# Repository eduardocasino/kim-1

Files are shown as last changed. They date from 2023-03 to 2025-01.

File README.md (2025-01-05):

# KIM-1 Replica

## Introduction

Welcome to the MOS KIM-1 reproduction project repository, where you will find what aims to be a faithful replica of the MOS KIM-1 computer, in particular a revision "D" PCB, based on photos and information gathered from various sources on the internet. With minimal modifications, later revisions should be easy to reproduce as well.

The KIM-1 was a single-board computer released in 1976 by MOS Technology, later acquired by Commodore, as a demonstrator of the capabilities of the recently released 6502 microprocessor.

## About

This recreation has been an excruciating process using entirely free software: Inkscape, Kicad and Freecad.

First, a high resolution image of a KIM-1 was used as a template in Inkscape. The image was resized to scale using the IC footprints as a reference. Then, the rest of the footprints were placed and the tracks were traced using bézier curves. I used a layer for each type graphic components (footprints, tracks, copper zones, typography, ...)

The logo was created from the MOS logo, adding the commodore name with the [Eurostile Extended 2 Bold font](https://fontsgeek.com/fonts/eurostile-extended-2-bold).

Component references where placed with the [Futura STD Bold font](https://fontsgeek.com/fonts/Futura-Std-Bold). The [Arial-like Aria font](https://fontsgeek.com/aria_1-font) was used for other typography.

The inkscape image was imported from Kicad to an user layer and used as a template for placing the footprints. Then, the image with the tracks was imported to the copper layer and converted to kicad tracks, so it was possible to check the pcb against the schematic.

The logo and the typography were converted to footprints using the svg2shenzhen plugin.

This is the end result:

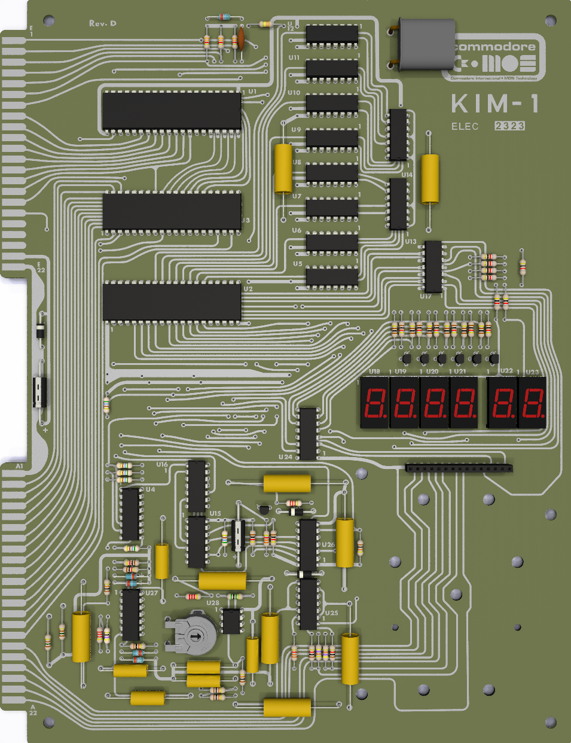
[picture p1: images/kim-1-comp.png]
components

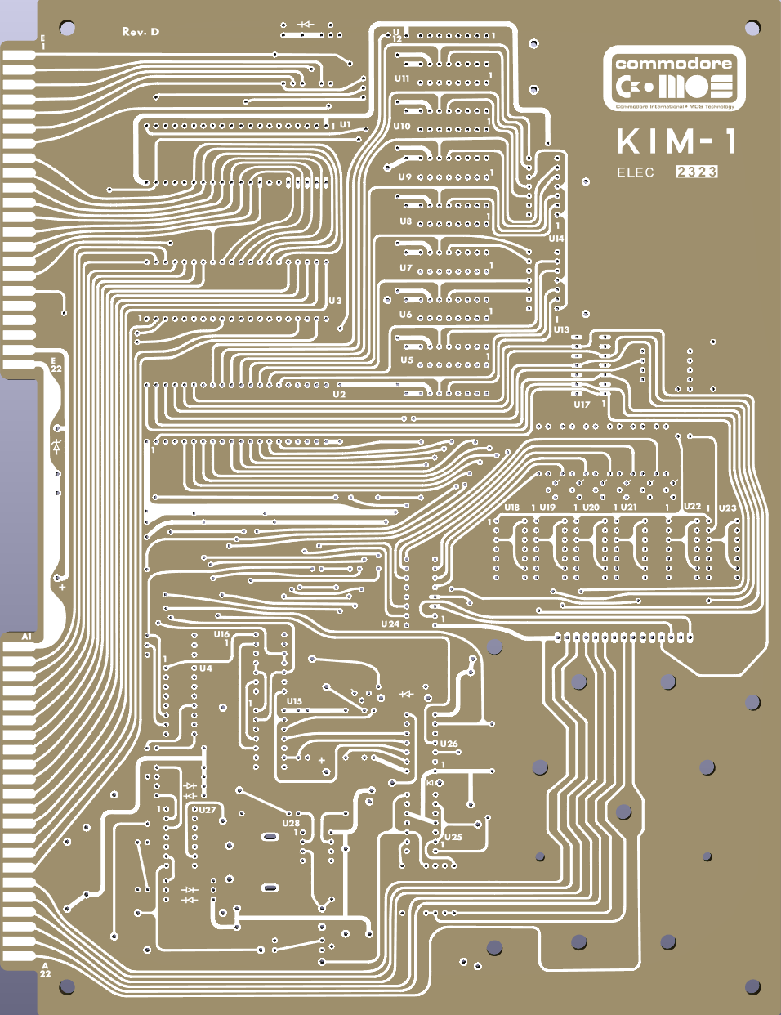
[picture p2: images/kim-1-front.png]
front

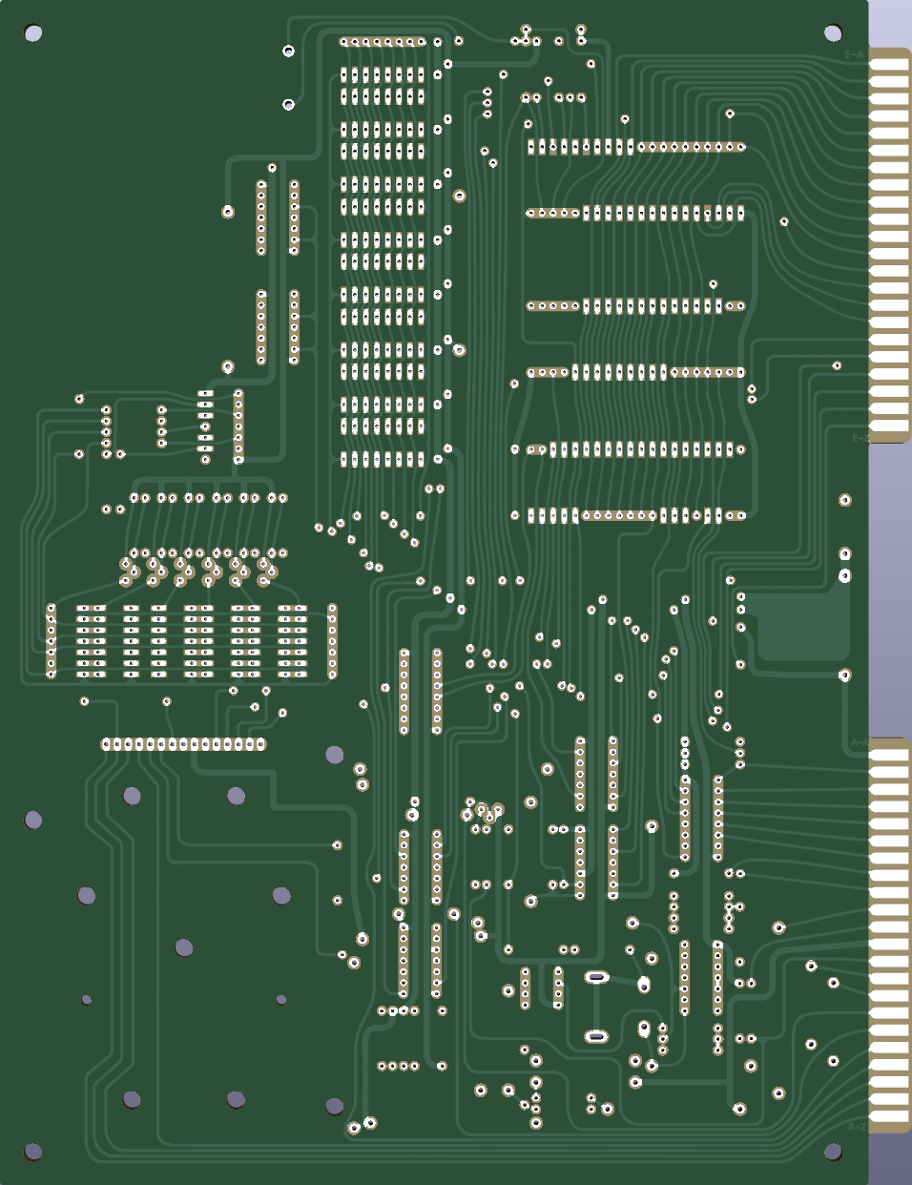
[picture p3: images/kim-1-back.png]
back


The replica has been successfully built and tested. Here is a picture of the KIM-1 working with [my dual 6530-6532 adapter](https://github.com/eduardocasino/kim-1-dual-6532-adapter) and [my work-in-progress kim-1 keypad](https://github.com/eduardocasino/kim-1-keypad):

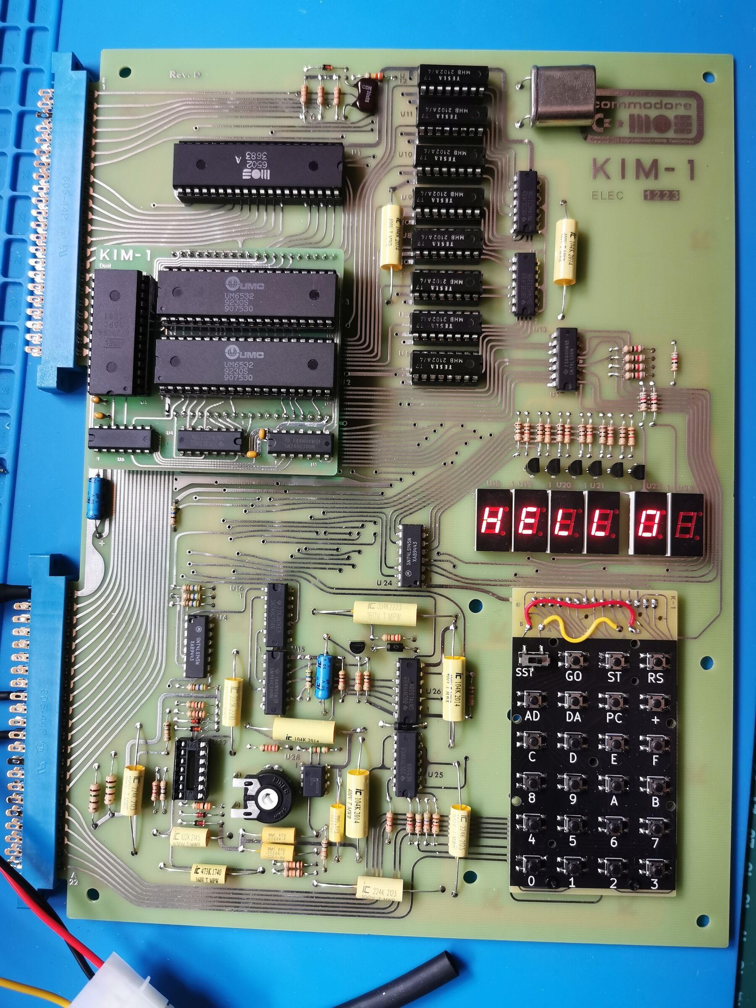
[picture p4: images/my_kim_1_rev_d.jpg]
KIM-1 replica working


## Building

[Paul Sajna](https://github.com/sajattack) has created an [Octopart BOM](https://octopart.com/bom-tool/09w2sZzv), with direct distributor links, to ease the sourcing of the components. Take into account that there are some obsolete parts that are no longer available, so you'll have to look on eBay or Aliexpress for them. Just be careful with counterfeits!

## Licensing

This is a personal project that I am sharing in case it is of interest to any retrocomputing enthusiast and all the information in this repository is provided "as is", without warranty of any kind.  



This work is licensed under a [Creative Commons Attribution-NonCommercial 4.0 International License](http://creativecommons.org/licenses/by-nc/4.0/).

EXCEPTION: The electrical schematic and all the associated symbols are licensed under a [Creative Commons Attribution 4.0 International License](https://creativecommons.org/licenses/by/4.0/).

See the LICENSE.md file for details.

## Changelog

#### 23/05/2023

* Fix position of mounting holes

#### 07/06/2023

* Fix tracks that weren't correctly imported from SVG
* Bump date stamp to week 2323
* Add interactive BOM

## Acknowledgements

* Hans Otten and his [Retro Computing blog](http://retro.hansotten.nl/). Tons of information and high resolution pictures of various KIM-1
* Chuck Hutchins, for his [hi-res scans of an unpopulated Rev. D PCB](http://retro.hansotten.nl/6502-sbc/kim-1-manuals-and-software/kim-1-revisions/)
* Budi Prakosa "badgeek" for the [svg2shenzhen](https://github.com/badgeek/svg2shenzhen) plugin for Inkscape
* qu1ck for his [interactive HTML BOM plugin](https://github.com/openscopeproject/InteractiveHtmlBom)
* Ralf (User ralf02 from forum64.de) for info on actual dimensions of a KIM-1 and ideas from [his thread on a KIM-1 clone](https://www.forum64.de/index.php?thread/124855-instandsetzung-und-nachbau-eines-kim-1/).
* [Armin Hierstetter](https://www.apple-1-replica.com/) for measurements of the mounting holes 
* [Paul Sajna](https://github.com/sajattack), for the Octopart BOM.

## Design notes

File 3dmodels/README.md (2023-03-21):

Donload the PT-15 potentiometer 3D model from here: https://www.piher.net/products/contacting-position-sensors/trimmers-and-control-potentiometers/through-hole/pt-15/

Make sure that the file is named PT15LV18.STEP

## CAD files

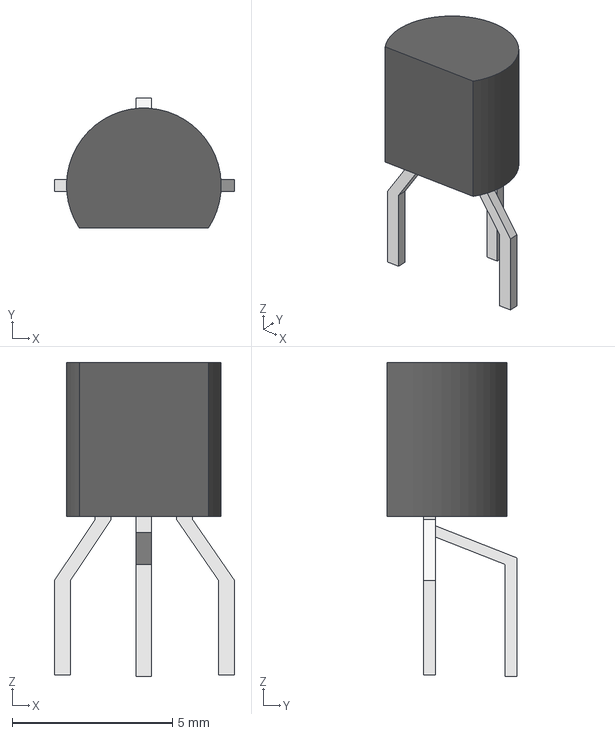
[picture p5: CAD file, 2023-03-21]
3dmodels/TO-92.step
5.62 x 4.06 x 9.80 mm

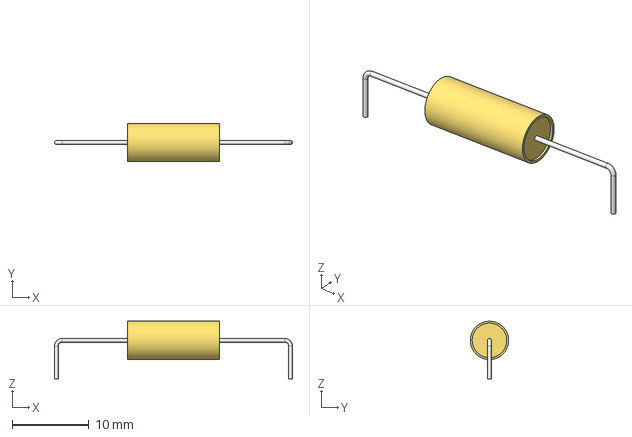
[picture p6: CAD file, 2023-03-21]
3dmodels/C_Axial_L12.0mm_D5.0mm_P30.48mm_Horizontal.step
31.0 x 5.00 x 7.50 mm
190bb9be-b13a-11ed-bc6f-67ea0efcc404_part
190bb9bf-b13a-11ed-bc6f-67ea0efcc404_part

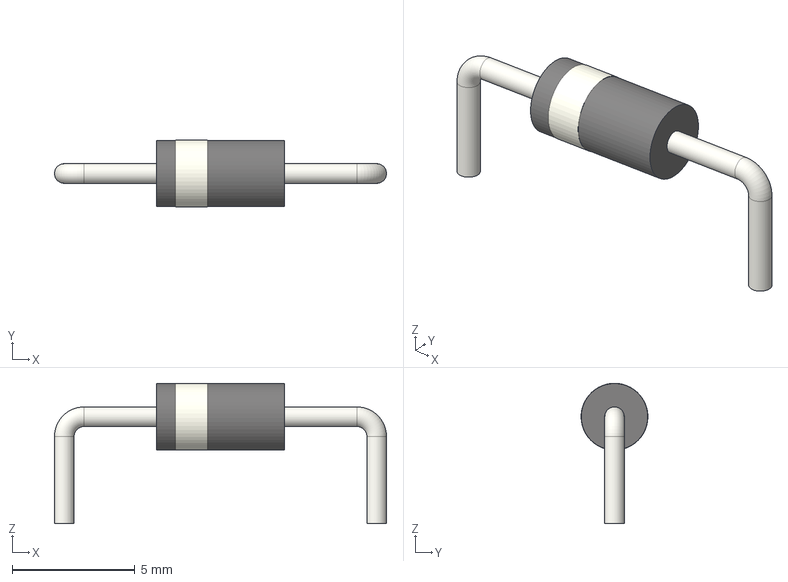
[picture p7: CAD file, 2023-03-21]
3dmodels/D_DO-41_SOD81_P12.30mm_Horizontal.step
13.5 x 2.72 x 5.71 mm

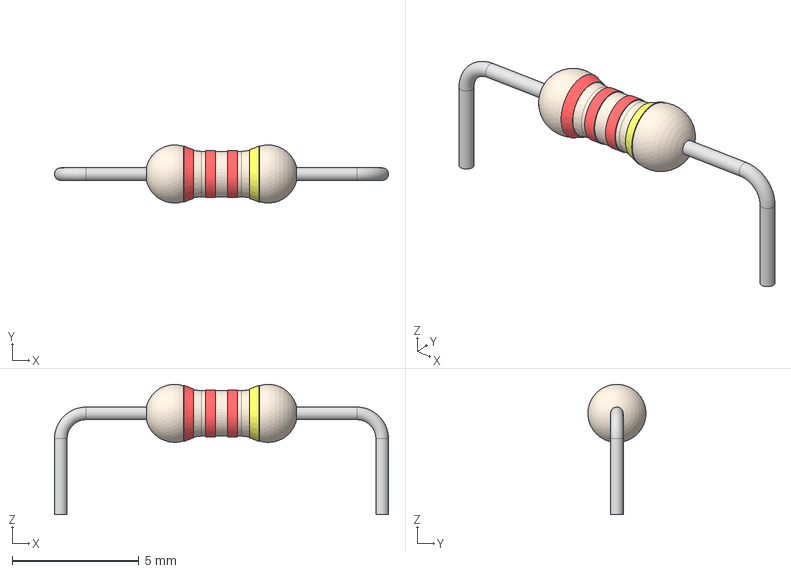
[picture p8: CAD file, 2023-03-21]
3dmodels/res-1_4w-2K2-12_7mm-Resistor-1_4w-220ohm.step
13.2 x 2.29 x 5.14 mm
Resistor-body
Ring-1
Ring-2
Ring-3
Ring-4
pins

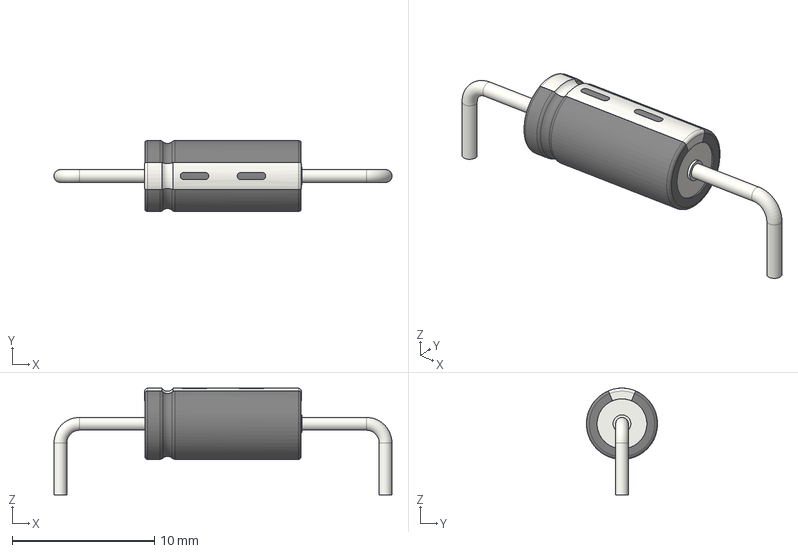
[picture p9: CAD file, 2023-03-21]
3dmodels/CP_Axial_L11.0mm_D5.0mm_P22.86mm_Horizontal.step
23.8 x 5.00 x 7.51 mm
190bb9ca-b13a-11ed-bc6f-67ea0efcc404_part
190bb9cb-b13a-11ed-bc6f-67ea0efcc404_part
190bb9cc-b13a-11ed-bc6f-67ea0efcc404_part
190bb9cd-b13a-11ed-bc6f-67ea0efcc404_part
190bb9ce-b13a-11ed-bc6f-67ea0efcc404_part

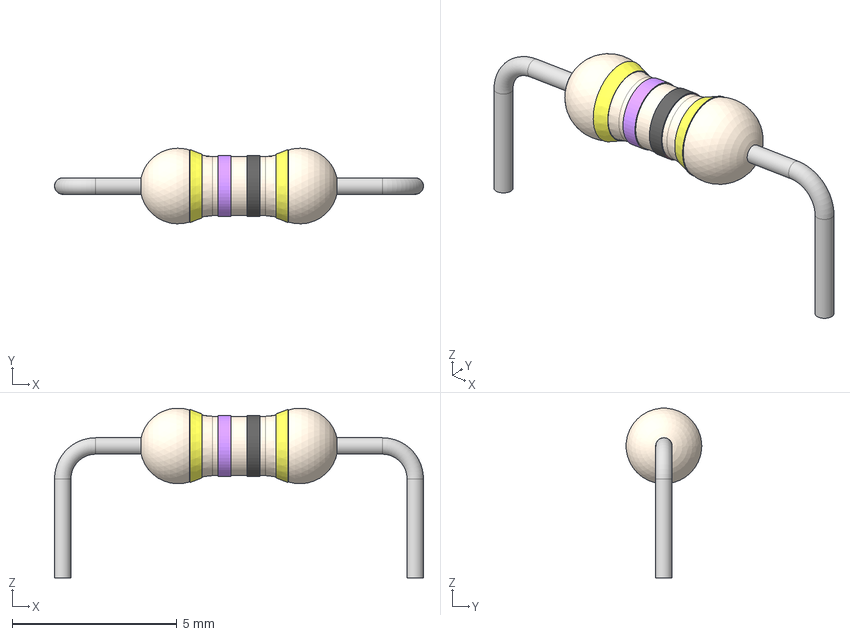
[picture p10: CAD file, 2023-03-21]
3dmodels/res-1_4w-47R-12_7mm-Resistor-1_4w-220ohm.step
11.2 x 2.29 x 5.14 mm
Resistor-body
Ring-1
Ring-2
Ring-3
Ring-4
pins

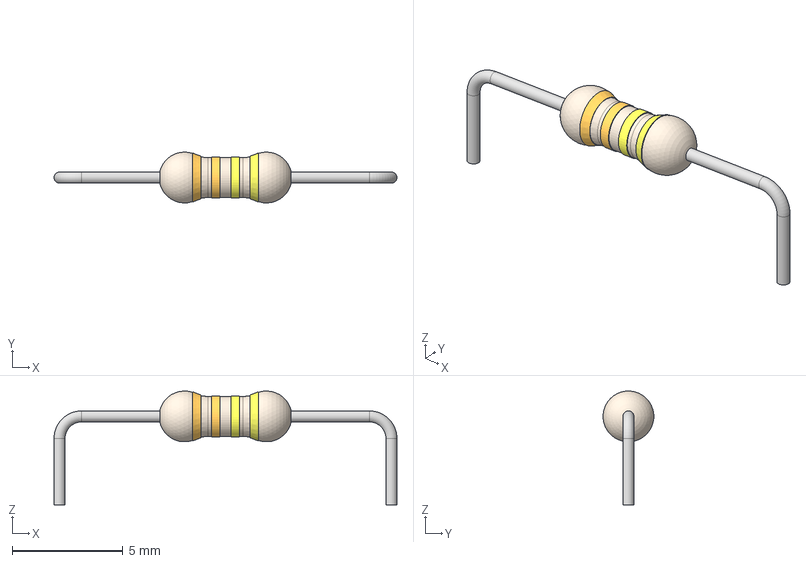
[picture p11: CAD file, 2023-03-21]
3dmodels/res-1_4w-330K-13mm-Resistor-1_4w-220ohm.step
15.5 x 2.29 x 5.14 mm
Resistor-body
Ring-1
Ring-2
Ring-3
Ring-4
pins

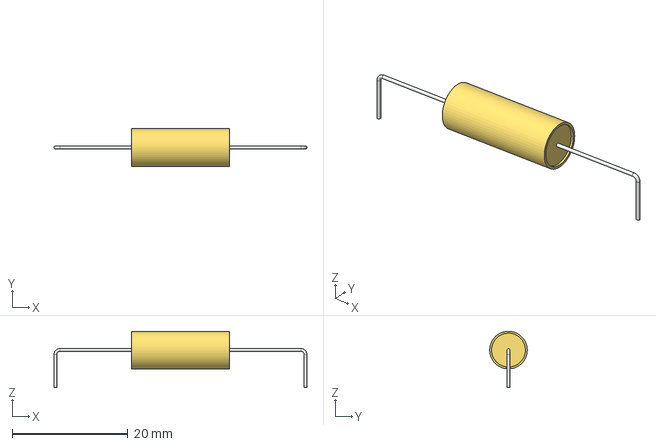
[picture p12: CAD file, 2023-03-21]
3dmodels/C_Axial_L17.0mm_D6.5mm_P43.18mm_Horizontal.step
43.7 x 6.49 x 9.75 mm
190bb9c7-b13a-11ed-bc6f-67ea0efcc404_part
190bb9c8-b13a-11ed-bc6f-67ea0efcc404_part

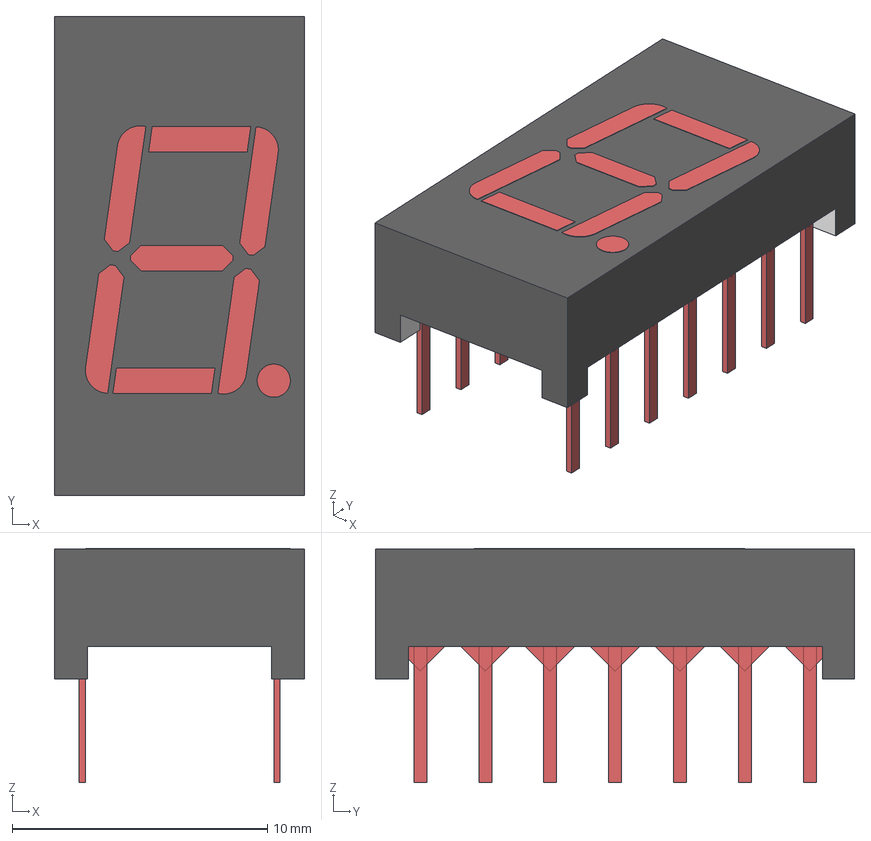
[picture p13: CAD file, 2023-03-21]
3dmodels/MANXXXX_A.step
9.80 x 18.8 x 9.16 mm
Leg001
Leg002
Leg003
Leg004
Leg005
Leg006
Leg007
Leg008
Leg009
Leg010
Leg011
Leg012
Leg013
Leg014
Digit001

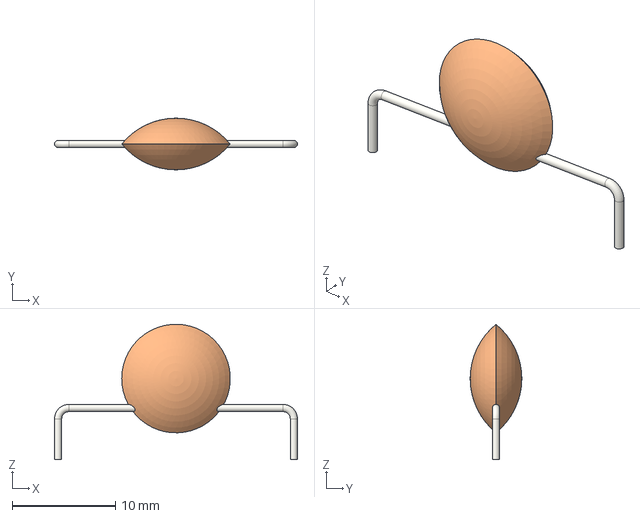
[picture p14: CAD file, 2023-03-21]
3dmodels/C_Disc_D10.5mm_W5.0mm_P22.80mm.step
23.5 x 5.00 x 13.1 mm
708d0071-afe8-11ed-bc6f-67ea0efcc404_part
708d0072-afe8-11ed-bc6f-67ea0efcc404_part

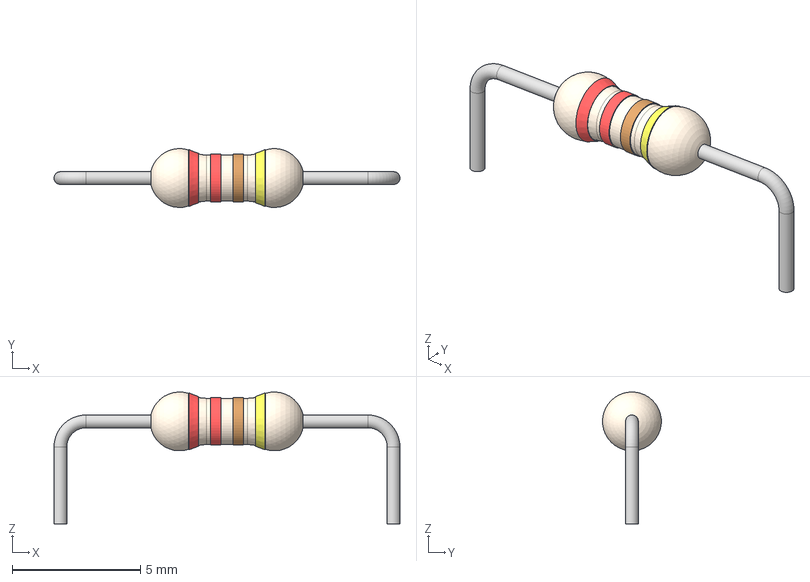
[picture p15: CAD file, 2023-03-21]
3dmodels/res-1_4w-220R-12_7mm-Resistor-1_4w-220ohm.step
13.5 x 2.29 x 5.14 mm
Resistor-body
Ring-1
Ring-2
Ring-3
Ring-4
pins

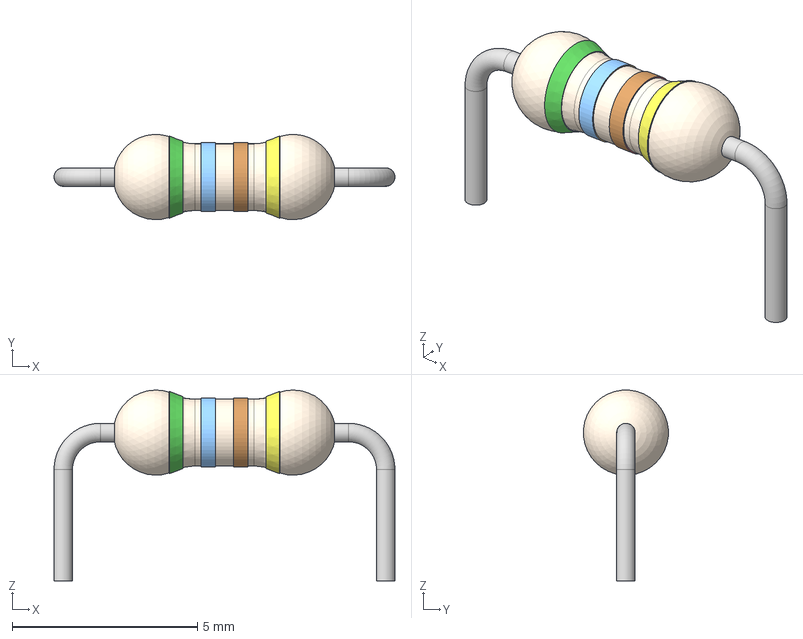
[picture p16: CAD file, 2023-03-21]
3dmodels/res-1_4w-560R-8_7mm-Resistor-1_4w-220ohm.step
9.20 x 2.29 x 5.14 mm
Resistor-body
Ring-1
Ring-2
Ring-3
Ring-4
pins

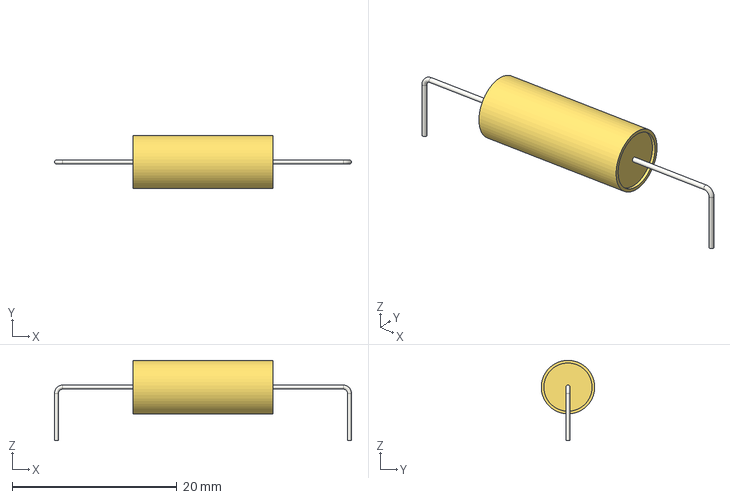
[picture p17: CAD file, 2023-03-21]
3dmodels/C_Axial_L17.0mm_D6.5mm_P35.56mm_Horizontal.step
36.1 x 6.49 x 9.75 mm
190bb9c1-b13a-11ed-bc6f-67ea0efcc404_part
190bb9c2-b13a-11ed-bc6f-67ea0efcc404_part

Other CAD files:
3dmodels/res-1_4w-5M-12_7mm-Resistor-1_4w-220ohm.step
3dmodels/res-1_4w-47K-12_7mm-Resistor-1_4w-220ohm.step
3dmodels/res-1_4w-1K-12_7mm-Resistor-1_4w-220ohm.step
3dmodels/res-1_4w-3K3-12_7mm-Resistor-1_4w-220ohm.step
3dmodels/res-1_4w-100R-12_7mm-Resistor-1_4w-220ohm.step
3dmodels/C_Axial_L12.0mm_D4.5mm_P22.86mm_Horizontal.step
3dmodels/C_Axial_L17.0mm_D6.5mm_P38.10mm_Horizontal.step
3dmodels/C_Disc_D9.0mm_W2.5mm_P13.00mm.step
3dmodels/res-1_4w-10K-12_7mm-Resistor-1_4w-220ohm.step
3dmodels/res-1_4w-150R-18_0mm-Resistor-1_4w-220ohm.step
3dmodels/res-1_4w-30K-12_7mm-Resistor-1_4w-220ohm.step
3dmodels/res-1_4w-3K3-13mm-Resistor-1_4w-220ohm.step
3dmodels/res-1_4w-560R-12_7mm-Resistor-1_4w-220ohm.step
3dmodels/res-1_4w-82R-12_7mm-Resistor-1_4w-220ohm.step

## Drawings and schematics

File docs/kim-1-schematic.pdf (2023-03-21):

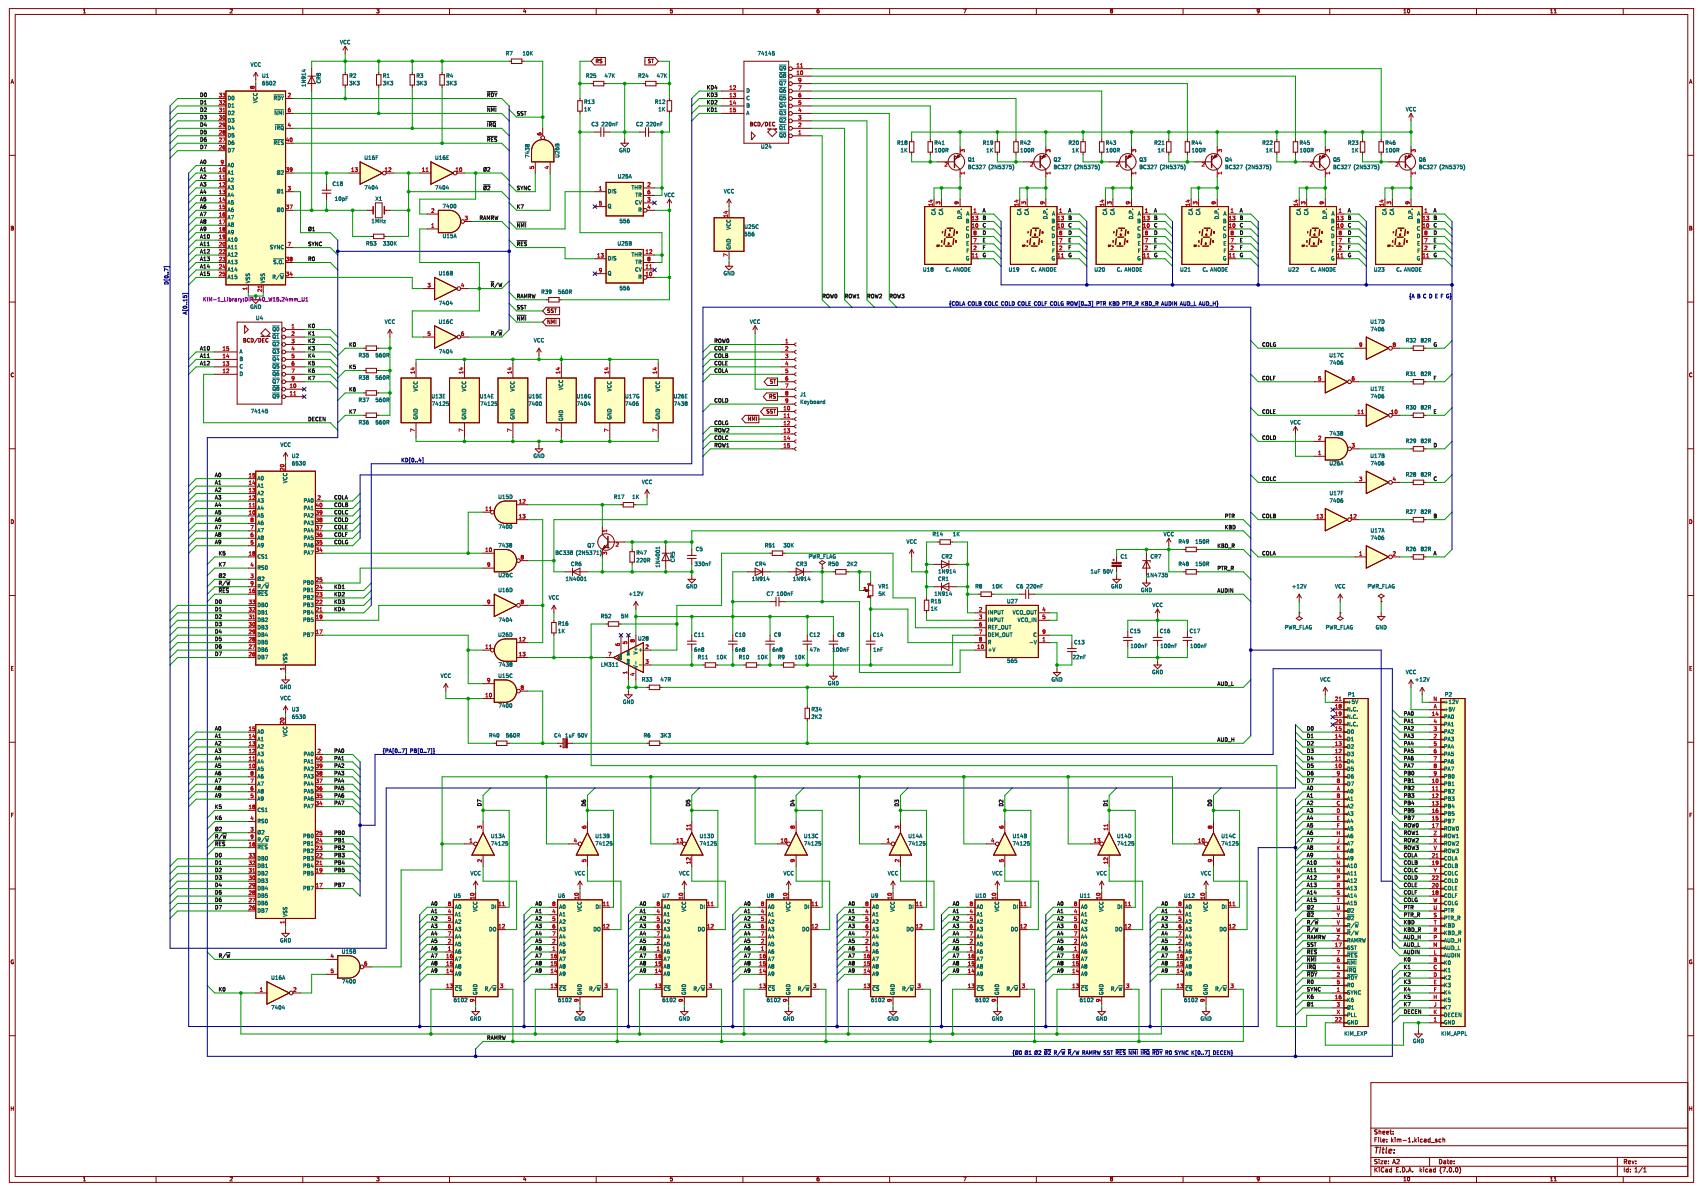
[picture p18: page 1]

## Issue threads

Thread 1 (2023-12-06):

Good resource for troubleshooting build?

ryaneroth, 2023-12-06:
Have you found any good resource for troubleshooting your build? I've completed mine, but I am getting nothing on the display. The signals on the 6502 appear to be correct, according to the user manual, but I'm looking for a better reference for testing signals around the board.

This is what I am currently using http://retro.hansotten.nl/uploads/6502docs/hwman.htm#34

(update)

My testing so far is leading me to something on the 6532 adapter board

eduardocasino, 2023-12-06:
I was lucky enough to have mine working at first try, so did not really have to do any troubleshooting. There is some information [on this thread](https://www.forum64.de/index.php?thread/124855-instandsetzung-und-nachbau-eines-kim-1/) (in German, but Google does a good job translating)

Excuse me if this is too obvious for you, but make sure that the DECEN signal is connected to ground (pins K and 1 of the application connector) and that you press the reset key after powering up.

Also, as you suspect the adapter board, could you please upload the full contents of the 8K EPROM so I can check that they are correct?

eduardocasino, 2023-12-06:
I think I see the problem. You have to program the EPROM starting at offset $1800, as instructed in [this issue](https://github.com/eduardocasino/kim-1-dual-6532-adapter/issues/1#issuecomment-1817937785). Yours starts at $0000.

ryaneroth, 2023-12-06:
I missed that at some point when re-flashing the EPROM, but even with that corrected, I'm seeing the same behavior.  Going to continue scoping out the adapter board.

[KIM-1-ROM.dump.zip](https://github.com/eduardocasino/kim-1/files/13588395/KIM-1-ROM.dump.zip)

Thanks

eduardocasino, 2023-12-06:
Try swapping the two RIOTs, the lower one (U2) is responsible for operating the display and keyboard. Also, do you have a way to test the memories? If not, you can use [this arduino based tester](https://www.8bity.cz/2013/jednoduchy-arduino-test-sram-mhb2102a-a-mm1101a/).

ryaneroth, 2023-12-09:
Just to circle back, I have four RIOTs, and I've tested them all in my PAL-1. I built the RAM tester, and sure enough, one of my modules fails 100% of the time for every bit.  I don't have any spares, so I am waiting on a replacement.  I'll update once I've installed a known good replacement.

ryaneroth, 2023-12-14:
Received some new RAM finally, fixed it!

Closed 2023-12-14.

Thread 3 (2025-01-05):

(Mostly) Purchasable BOM

sajattack, 2025-01-05:
Hello,

I noticed the BOMs in your repo are a bit vague and had difficulty finding the right components while building my board.

So I created a octopart BOM which is currently 84% procurable with direct distributor links.

Hope this helps

https://octopart.com/bom-tool/09w2sZzv

eduardocasino, 2025-01-05:
Thanks! Adding a link to ethe BOM into the README. Hope you are having fun with your replica :wink:

Closed 2025-01-05.

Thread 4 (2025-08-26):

LM565cn

dinnes4-design, 2025-08-26:
Hi,

I'm looking to build one of your boards, but I am trying to source a LM565cn. I notice on the picture on the readme that it is missing and the KIM-1 seems to work without it, is that correct?

Also is there an alternative to the LM565cn you could recommend such as a 74HC4046?

Thanks

David.

eduardocasino, 2025-08-27:
Hi David,

AFAIK, there’s no direct 1:1 replacement for the LM565. I believe I got mine from eBay, but make sure to buy only from trusted sellers.

That chip is only required for the cassette interface, so you can skip it if you’re not planning to use tapes.

Best,
Eduardo

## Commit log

2023-03-21 3D models cleanup
    [C_Axial_L12.0mm_D5.0mm_P22.86mm_Horizontal.step, PT15LV18.STEP, res-1_2w-150R-12_7mm.step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]
2023-04-04 Update gerbers to latest changes
    [kim-1-B_Cu.gbl, kim-1-B_Mask.gbs, kim-1-Edge_Cuts.gm1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]
2023-04-04 Add explicit front solder mask
2023-05-22 Update hole footprints
2023-05-22 Fix positions of mounting holes
    [kim-1-B_Cu.gbl, kim-1-B_Mask.gbs, kim-1-Edge_Cuts.gm1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]
2023-05-24 Bring back texts on copper layers
    [kim-1-B_Cu.gbl, kim-1-B_Mask.gbs, kim-1-F_Cu.gtl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]
2023-05-25 Update fabrication parameters and files
    [kim-1-B_Cu.gbl, kim-1-B_Mask.gbs, kim-1-B_Paste.gbp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]
2023-06-07 Fix tracks that weren't correctly imported from SVG
    [kim-1-F_Cu.gtl]
2023-06-07 Bump date stamp to week 2323
    [kim-1-F_Cu.gtl]
2023-06-07 Add interactive BOM
2023-06-07 Fix tracks, bump date stamp, add interactive BOM
2023-06-26 Board is built now, remove warning
2025-01-05 Adding link to Paul Sajna's BOM. Closes Issue #3

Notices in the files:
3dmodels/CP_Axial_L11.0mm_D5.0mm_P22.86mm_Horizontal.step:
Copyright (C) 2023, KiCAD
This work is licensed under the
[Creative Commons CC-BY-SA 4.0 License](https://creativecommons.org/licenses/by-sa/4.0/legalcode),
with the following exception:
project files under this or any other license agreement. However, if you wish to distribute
